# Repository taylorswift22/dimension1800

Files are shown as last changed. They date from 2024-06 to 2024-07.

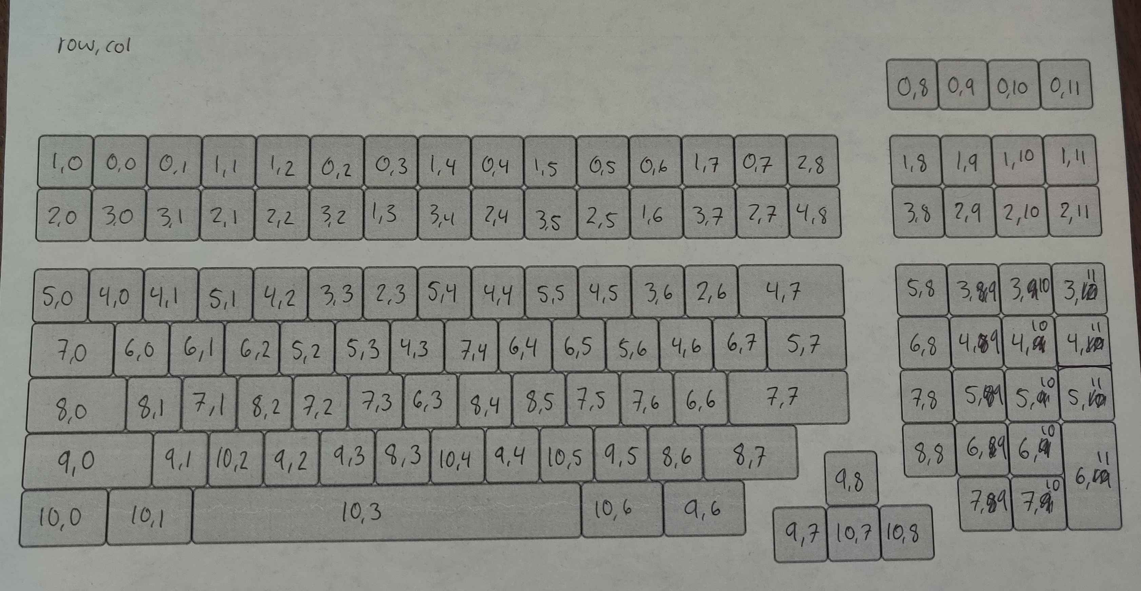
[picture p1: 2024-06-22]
matrix.jpg

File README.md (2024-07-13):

# dimension1800

USB QMK-compatible PCB for the Siemens 10453443 / KBA-D2911

2b5b1c4b-f160-424f-aae0-397b622dffc3

3cb45aca-eae0-463b-8944-8dda7efd8b32

## Information

This PCB accepts THT or SMD diodes. It requires either the use of an elite-pi (https://docs.keeb.io/elite-pi-guide) or a Raspberry Pi Pico. The elite-pi is positioned so that when it is soldered correctly, the USB-C port is easily accessible from the back of the PCB. The elite-pi is the recommended MCU for this PCB. The Raspberry Pi Pico is the backup in case the elite-pi becomes no longer available - it is positioned further inside the keyboard, so it would result in a "fixed" cable.

I have not tested the PCB with SMD diodes or the Raspberry Pi Pico. Production files are included for SMD diode assembly at JLCPCB.

The keyboard originally uses a plate and PCB. This PCB is designed to be used plateless.

## Spacebar Stabilizer

My keyboard is a KBA-D2911**C** with a 7u PBT spacebar with nonstandard stabilizer spacing. You will most likely want to re-use the original spacebar stabilizer wire or make your own. Some other versions appear to have an ABS spacebar - I do not know what the spacing for the ABS spacebars is. The PCB can accept either the standard Cherry 7u spacing or the nonstandard PBT spacebar spacing.

## Elite-Pi soldering

In order for the USB-C port on the elite-pi to be accessible, you must solder the elite-pi away from the PCB like this:

4c59b271-36fa-4435-825e-fdf1b599cb85

0a84e36f-0fb4-41b7-b86e-02bf23a067df

## Arrow key position

On my prototype, the arrow keys appeared to be slightly too far up and to the right.

71f76bc1-6a32-4076-b67d-1b09a6f14d8f

I have moved the arrow keys down and to the left by 0.25mm in the current version.

## Production files
To order, navigate to dimension-PCB/jlcpcb/production_files and copy what you need. If you choose THT diodes, just upload GERBER-dimension-PCB.zip. The BOM and CPL file are for SMD diode assembly at JLCPCB.
I have 4 prototypes with the slightly misaligned arrow keys. You can contact me on discord if you wish to purchase one for free + the cost of shipping.

## Firmware
Coming soon.

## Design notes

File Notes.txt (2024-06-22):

34+30+58=122 keys

we need one pin for LED
122 matrix positions plus one pin for LED

we have 11 rows and 12 columns.
Need 23 Matrix + 1 LED pin = 24 total IO pins.

pico footprint source: ctrl + f kicad https://datasheets.raspberrypi.com/pico/pico-datasheet.pd

spacebar stab:
stab wire diameter: 1.6mm
Distance from stem to stem = 110.18

110.18/2 = 55.09

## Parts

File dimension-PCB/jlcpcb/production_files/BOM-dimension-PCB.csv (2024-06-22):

Comment | Designator | Footprint | LCSC
1k | R1 | R_0603_1608Metric | C21190
D_Small | D1,D10,D100,D101,D102,D103,D104,D105,D106,D107,D11,D111,D112,D113,D114,D115,D116,D117,D118,D12,D122,D123,D124,D125,D126,D127,D128,D13,D14,D15,D16,D17,D18,D19,D2,D20,D21,D22,D23,D24,D25,D26,D27,D28,D29,D3,D30,D31,D32,D33,D34,D35,D36,D37,D38,D39,D4,D40,D41,D42,D43,D44,D45,D46,D47,D48,D49,D5,D50,D51,D52,D53,D54,D55,D56,D57,D58,D59,D6,D60,D61,D62,D63,D64,D65,D66,D67,D68,D69,D7,D70,D71,D72,D73,D74,D75,D76,D77,D78,D79,D8,D80,D81,D82,D83,D84,D85,D86,D87,D88,D89,D9,D90,D91,D92,D93,D94,D95,D96,D97,D98,D99 | D_SOD-123_THT_Back | C8598
Pico | U1 | RPi_Pico_SMD_TH_Alt
